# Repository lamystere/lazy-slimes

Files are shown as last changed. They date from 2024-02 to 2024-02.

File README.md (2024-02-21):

# lamystere's lazy slimes
#### Tutorial and 3d print files for the easiest slime build possible
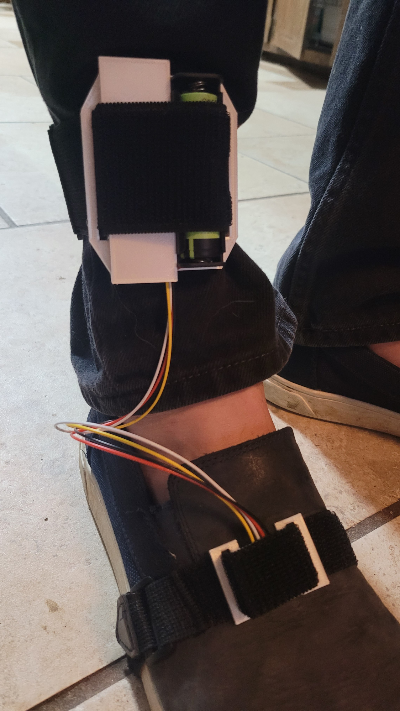
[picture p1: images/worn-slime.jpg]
a slime worn

### Pros  
- Quick to build: Each pair of trackers takes less than 15 minutes.
<sub><sup>(your soldering times may vary)</sup></sub>
- You'll have battery life for days.  About 36 hours run time.
- You can swap out low batteries for fresh ones.
- The only tools needed are a 3d printer, soldering iron, and scissors.
### Cons
- Putting batteries in backwards will kill your d1 board unless you add the diode!!!
- No battery percentage indication.
<sub><sup>(D1s will brown out before 18650s reach a harmfully low voltage.  Just be sure to remove the battery after the tracker dies or it will continue draining)</sup></sub>
- The battery makes it bigger than stock slimes. Its the size of Frozen Slimes.
- You'll have to remove the batteries to charge them or turn off the slimes.

## Parts for 10 trackers: $51 using AliExpress, $87 using amazon  
-  4-pin 2.54mm JST cables+connectors:  $8 - 19  
([30cm x 20 for \$8 on AliExpress](https://www.aliexpress.us/item/3256804651533419.html) - These have right angle connectors included so you save $6)  
([100cm x 4 for \$11 on AliExpress](https://www.aliexpress.us/item/3256805863323549.html) - optional for longer runs to satellites)  
([30cm x 20 for \$8 on amazon](https://www.amazon.com/dp/B09JNZJXTF))  
([100cm x 5 for \$11 on amazon](https://www.amazon.com/Kidisoii-Connector-Pre-Crimped-Housing-Adapter/dp/B0BW9T2L26) - optional for longer runs to satellites)  
-  4 pin female right-angle JST connectors:  $6  <sub><sup>(not needed if sourced from AliExpress)</sup></sub>  
([bag of 50 for \$6](https://www.amazon.com/dp/B0BMDQLR4Q))  
- D1 Minis: \$5 - \$15 for 10 tracking points  
([$1 each at AliExpress](https://www.aliexpress.us/item/3256805974392372.html))  
([$3 each at amazon](https://www.amazon.com/dp/B081PX9YFV))  
<sub><sup>([Tiel brought to my attention the Wemos Wroom has an integrated 18650 for roughly the same price.  Maybe that will be the next version.](https://www.aliexpress.us/item/3256804461622366.html)</sup></sub>
- BMI 160s: \$15 - \$21 for 10 tracking points  
([$1.50 each from AliExpress](https://www.aliexpress.us/item/3256805412351566.html))  
([$2 each at amazon if you can't wait, but buyer beware](https://www.amazon.com/dp/B0C4TMKL3V))*  
<sub><sup>*I linked ones that worked for me but you should avoid Amazon due to flaky QA.  You may get up to 50% DOA from some sellers.</sup></sub>
- Battery holders: \$6 - \$8  
([10 for \$6 on aliexpress](https://www.aliexpress.us/item/3256805903232291.html))  
([10 for \$8 on amazon](https://www.amazon.com/HiLetgo-10pcs-Battery-Holder-Storage/dp/B00LSG5BKO))   
- 18650 batteries and charger: \$16 - \$29 + optional \$12 - \$20 for a bigger charger  
([\$16 for 8 batteries and 2 bay charger](https://www.aliexpress.us/item/3256806110185068.html) on AliExpress)  
([\$12 for an 8 slot charger](https://www.aliexpress.us/item/3256806302334830.html) on AliExpress)  
([6 batteries and 4 slot charger for $29 on amazon](https://www.amazon.com/Tokeyla-Rechargeable-6-Button-top-B%EF%BF%B5at%EF%BF%B5t%EF%BF%B5%EF%BF%B5ery-Ba%EF%BF%B5tt%EF%BF%B5%EF%BF%B5er%EF%BF%B5y/dp/B0CBRDVHTY/))  
(or [6 batteries and 2 slot charger for $25](https://www.amazon.com/1%EF%BF%B58%EF%BF%B56%EF%BF%B550-Rechargeable-Batter%EF%BF%B5y-Universal-Batteries/dp/B0CLZTS43N/) on amazon)  
([6 bay charger for $17](https://www.amazon.com/Battery-Universal-Rechargeable-Batteries-Compatible/dp/B091GDK56V) on amazon)  
- 1n5817 Diodes: <sub><sup>(optional protection from putting the battery in backwards.  You should probably be less lazy than me and get them.)</sup></sub>  
[$5 for 100 at AliExpress](https://www.aliexpress.us/item/3256806265356485.html)  
[$7 for 100 at amazon](https://www.amazon.com/100-Pieces-1N5817-Schottky-Rectifier/dp/B079KDQQPD)  
- 3d printed cases: priceless  
- I'm assuming you have a soldering iron  

### Straps:
Consult [the slime VR docs for some good DIY strap ideas](https://docs.slimevr.dev/diy/diy-straps.html) to match your sewing skills.  Stretchy straps are very necessary! Regular velcro/nylon will fall right off.  If you just want to buy everything here's the amazon solution for \$40:
-  Stretchy 1" and 2" straps:  $26
([two of these at \$13](https://www.amazon.com/dp/B08CDGZ774))
([or one and this pack for \$12](https://www.amazon.com/VELCRO-Brand-VEL-30794-AMS-Stretchable-Umbrellas/dp/B09QSYVP5H))
- Chest harness: \$14
([\$14 for the cheapest gopro holder](https://www.amazon.com/dp/B01D3I8A7A))

# Cases
These are modeled after [Frozen Slimes](https://github.com/frosty6742/frozen-slimes-v2) but without the fancy PCB.  If you just want to print them you can use the [included STL files](/case-files/stl/) to slice and print.  If you have an Ender3 and PLA you can skip slicing and use the [included gcode files](/case-files/gcode%20for%20ender3/).  
   
The [master file](/case-files/lazy-slimes.scad) is written in [OpenSCAD](https://openscad.org/). You will need to use that to customize it (Fork it and send me a PR!).  Check out the parameters at the top for isolating each piece.  
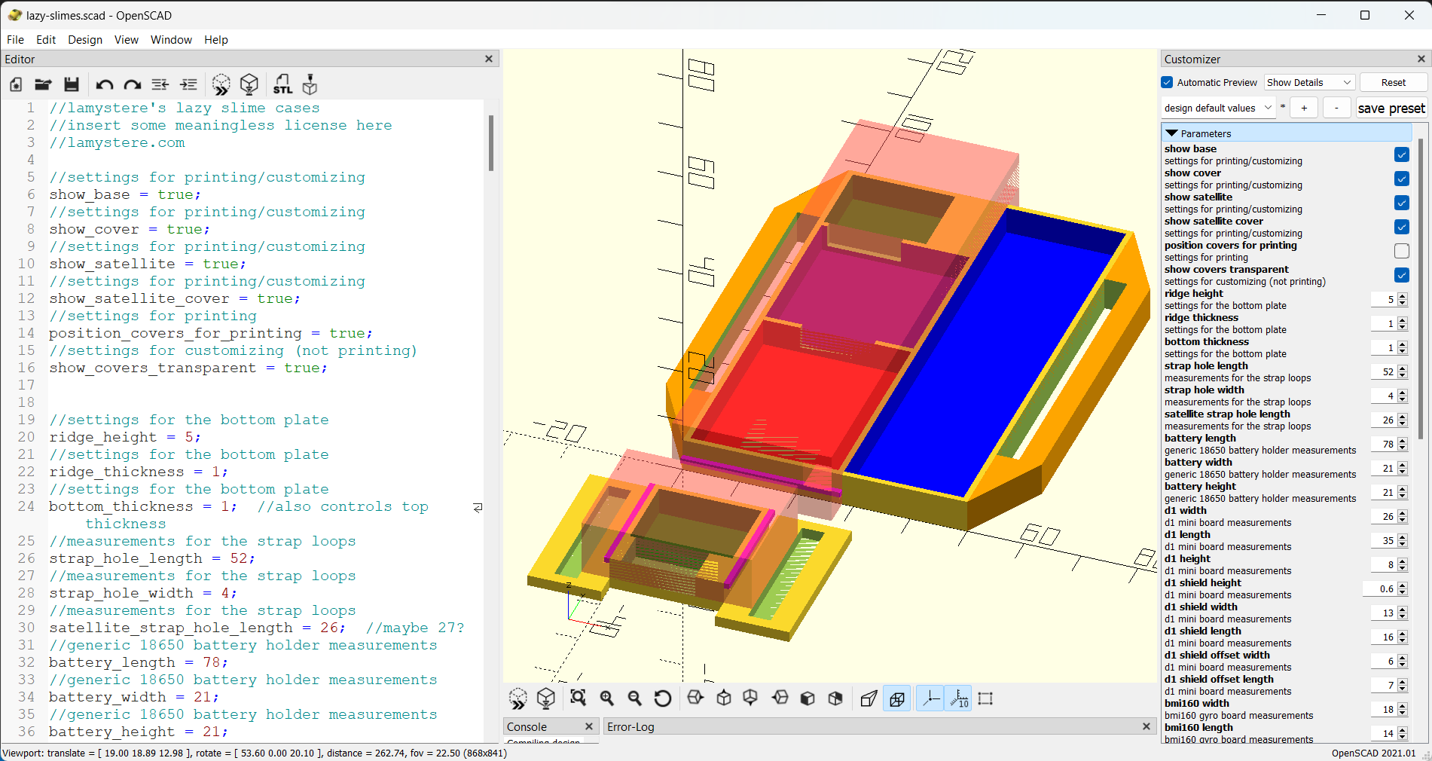
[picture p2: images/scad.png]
screen shot of scad file


# Building
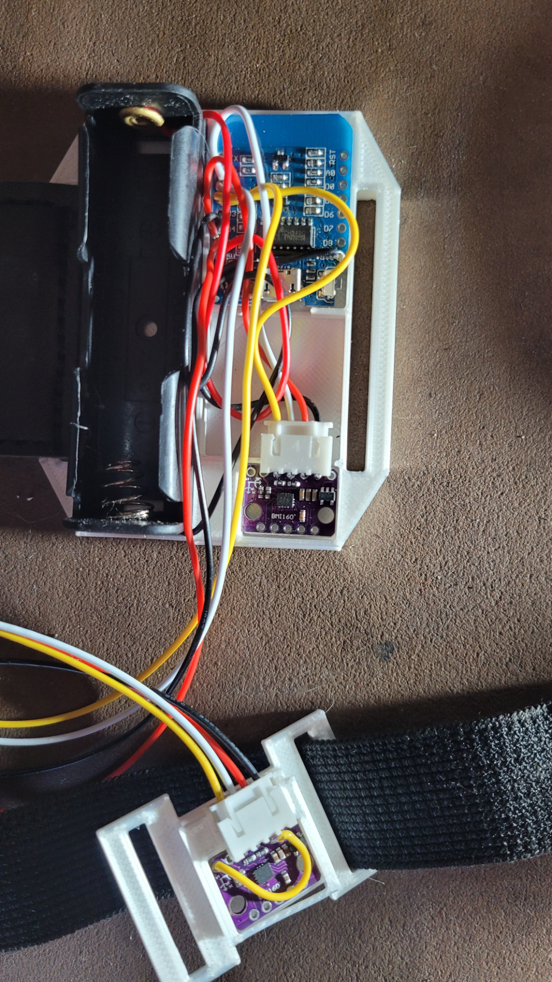
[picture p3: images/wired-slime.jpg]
a wired slime tracker

<sub><sup>(youtube walk-through is in the works)</sup></sub>

1. Cut one of the 4 pin jst cables to about the length of the case and strip the ends of the now shorter cable.
1. Solder the right angle connectors to the BMI160 boards covering the pins from 3v3 to SDA on the side with the parts.
2. Plug the long and short cables in to the BMI160s so you can follow the pad labels. Use the 100cm cables for longer runs like waist to chest or waist to thighs.  The cheaper 30cm cables should be enough for all the rest.  
<sub><sup> If you want to save \$11 you could omit the 100cm cables and make extensions by soldering a female jst connector onto a 30cm cable.  
If you don't need a satellite sensor connected you can skip the longer cable entirely.</sup></sub>
1. Use a scrap of the wire you just cut to solder a jumper on the satellite BMI160 from the G pad to the SAO pad. <sub><sup>This is necessary to identify it as sensor #2 on the data bus.</sup></sub>
1. Insert the battery ground wire and the ground wire for both BMI160s* into the G pad on the D1.  This is the trickiest part of the build but all 3 WILL fit in the hole.  Solder them all in. <sub><sup>(*note: to keep things quick ignore the color of the jst wires.  The G wire should be the second pad from the top on the BMI160)</sup></sub>
1. Solder the red battery wire into the 5V pad of the D1.  If you chose to get protection diodes then cut the red wire from the front of the battery holder and solder the diode there.  Reattach the red wire to the end of the diode with the ring painted on it.
1. Solder both of the 3V3 leads from the BMI160s to the 3V3 pad of the D1
1. Solder both of the SCL leads from the BMI 160s to the D1 pad of the D1
1. Solder both of the SDA leads from the BMI 160s to the D2 pad of the D1
1. Configure and connect to the wifi and Slime Server using a usb cable to the D1.  Configure and upload Slime firmware to the D1 first if you haven't already.  [Instructions](https://docs.slimevr.dev/firmware/index.html) and <a href="data:text/plain;charset=utf-8,%23define%20IMU%20IMU_BMI160%0A%23define%20SECOND_IMU%20IMU_BMI160%0A%23define%20BOARD%20BOARD_WEMOSD1MINI%0A%23define%20IMU_ROTATION%20DEG_90%0A%23define%20SECOND_IMU_ROTATION%20DEG_90%0A%0A%23define%20PRIMARY_IMU_OPTIONAL%20false%0A%23define%20SECONDARY_IMU_OPTIONAL%20true%0A%0A%23define%20MAX_IMU_COUNT%202%0A%0A%23ifndef%20IMU_DESC_LIST%0A%23define%20IMU_DESC_LIST%20%5C%0A%20%20%20%20IMU_DESC_ENTRY(IMU%2C%20%20%20%20%20%20%20%20PRIMARY_IMU_ADDRESS_ONE%2C%20%20%20IMU_ROTATION%2C%20%20%20%20%20%20%20%20PIN_IMU_SCL%2C%20PIN_IMU_SDA%2C%20PRIMARY_IMU_OPTIONAL%2C%20%20%20PIN_IMU_INT)%20%5C%0A%20%20%20%20IMU_DESC_ENTRY(SECOND_IMU%2C%20SECONDARY_IMU_ADDRESS_TWO%2C%20SECOND_IMU_ROTATION%2C%20PIN_IMU_SCL%2C%20PIN_IMU_SDA%2C%20SECONDARY_IMU_OPTIONAL%2C%20PIN_IMU_INT_2)%0A%23endif%0A%0A%2F%2F%20Battery%20monitoring%20options%20(comment%20to%20disable)%3A%0A%2F%2F%20BAT_EXTERNAL%20for%20ADC%20pin%2C%20BAT_INTERNAL%20for%20internal%20-%20can%20detect%20only%20low%20battery%2C%20BAT_MCP3021%20for%20external%20ADC%0A%23define%20BATTERY_MONITOR%20BAT_EXTERNAL%0A%23define%20BATTERY_SHIELD_RESISTANCE%20180%20%2F%2F130k%20BatteryShield%2C%20180k%20SlimeVR%20or%20fill%20in%20external%20resistor%20value%20in%20kOhm%0A%0A%23define%20PIN_IMU_SDA%20D2%0A%23define%20PIN_IMU_SCL%20D1%0A%23define%20PIN_IMU_INT%20D5%0A%23define%20PIN_IMU_INT_2%20D6%0A%23define%20PIN_BATTERY_LEVEL%20A0%0A">defines.h</a>
1. Place the BMI160 with the shorter wires into the top of the main case, the D1 into the bottom with wifi shield down, and the battery holder into the longest slot.
1. Place the base and cover on a flat surface to help line them up.  Slide the cover over the electronics.  Tuck the shorter cable and battery wires under the cover as you slide it.  Run the longer cable out the notch in the top or bottom. 
<sub><sup>To keep all BMI160 sensors pointed towards the ceiling you should run it through the hole nearest to the BMI160.  The BMI160 connector should always point towards the ceiling.  If that's not convenient you could [re-flash your firmware to customize the sensor orientation](https://docs.slimevr.dev/firmware/configuring-project.html#configuring-definesh-automatically).  Feet seem to be the exception.</sup></sub>  
1. Insert the satellite sensor into its little case and slide the cover over it
1. Thread the straps through the sides of cases over the battery slot so it can hold the battery in.  
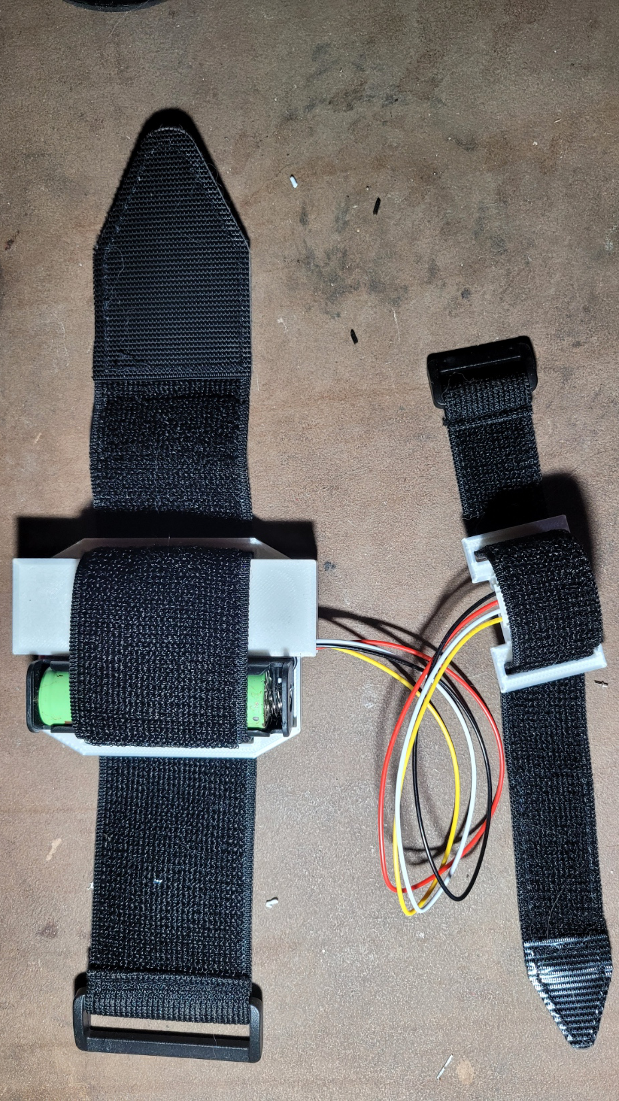
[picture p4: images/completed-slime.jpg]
a completed slime tracker


# Placement example
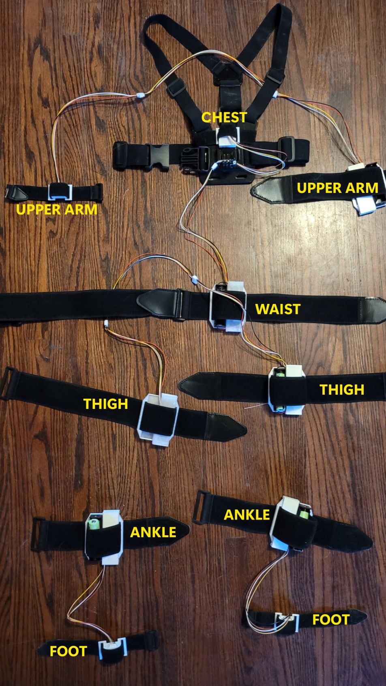
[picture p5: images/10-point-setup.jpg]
a 10 tracking point setup

1. Make sure all BMI160s have the connectors facing the ceiling (except the feet).  You may want to draw an arrow on the cover to indicate the "up" side of the tracker.
1. Combine 2 straps to reach around your waist.  
1. Notice that for one thigh I used a full size case just to hold a BMI160.  This is to accomodate needing a 2" strap to reach around a thigh.  I thread the cord over the waistband so it doesn't float between my legs.  <sub><sup>This would be a good case for having 2 independent trackers, but for this example of 5 trackers with 5 satellites I think it works best.  Some people connect one thigh to the waist sensor and the other thigh to the hip sensor.</sup></sub>
1. Its a similar dilemma with the upper arm sensors, but the 1" strap can reach around my bicep so its easier to keep to the standard setup and simply have a longer cord.  Notice I used 30cm extension cables rather than starting with a 100cm cable.

#### 12 point example:
Same except with lower arms.  Some may prefer shoulders instead.  
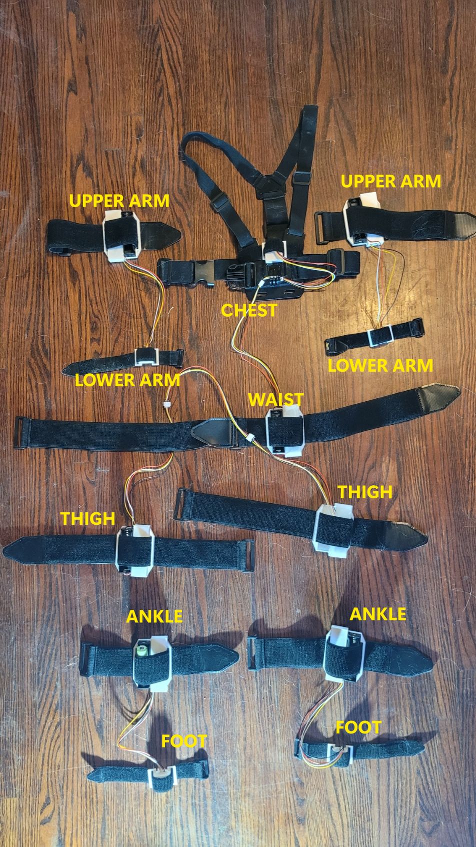
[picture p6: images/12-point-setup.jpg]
a 12 tracking point setup
  
Why not add in another 4 and get upper chest, waist, shoulders and lower arms?  Why stop there?  With 20 points you could get head, neck, and hands too and ditch the HMD for mocap purposes.  Then you only need finger tracking gloves!  And don't forget to strap a phone on to capture your face!

# Putting it on
1. Loosen the straps and insert all the batteries.  
<sub><sup>(Put red tape on the positive end of both the battery and the holder if you're worried you might accidentally insert it backwards)</sup></sub>
1. Tap the trackers while watching the slime server to confirm they are all connected and which is which.
1. Sit down and put on the waist band first.
1. Put on the harness with the chest sensor.
1. Strap remaining sensors around arms, legs and feet.
1. [Calibrate](https://docs.slimevr.dev/server/imu-calibration.html), [calibrate](https://docs.slimevr.dev/server/configuring-trackers.html), [calibrate](https://docs.slimevr.dev/server/body-config.html)!
1. Dance, dance, dance!
1. Remove the batteries to turn them off or when you need to charge.

# Thanks
Thanks to Gorbit99 and Tiel for suggesting improvements to this build!

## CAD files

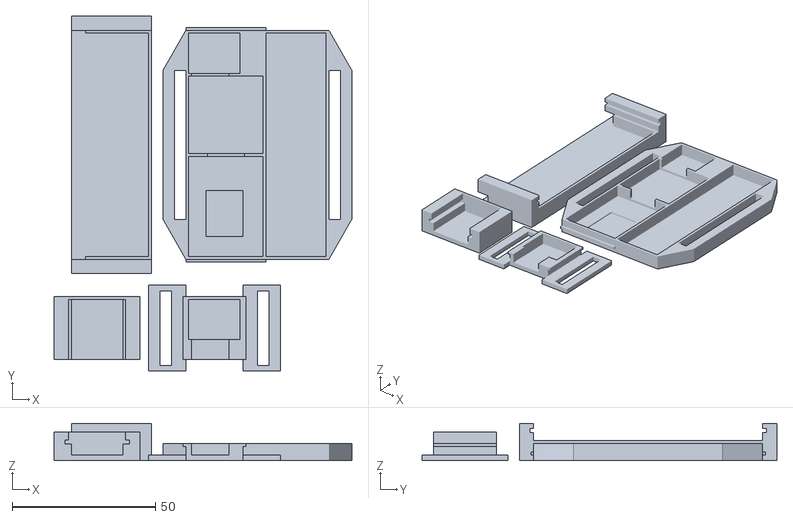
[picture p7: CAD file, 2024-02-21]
case-files/stl/whole_set.stl
104.0 x 124.0 x 13.0

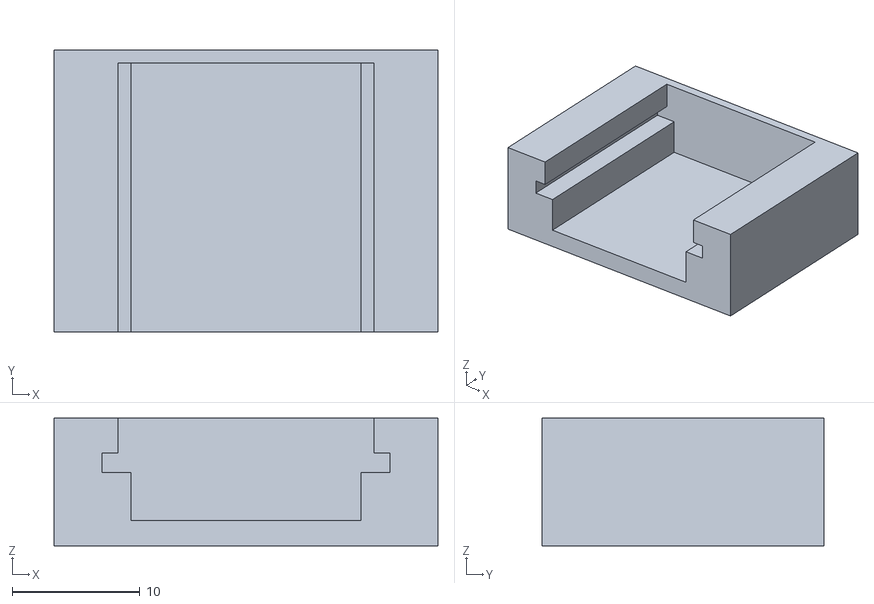
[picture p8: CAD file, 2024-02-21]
case-files/stl/satellite_cover.stl
30.0 x 22.0 x 10.0

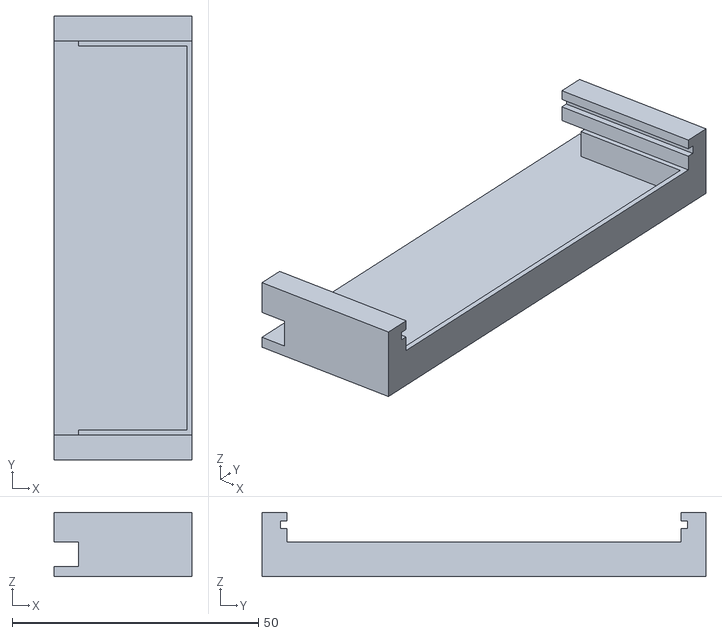
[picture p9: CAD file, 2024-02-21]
case-files/stl/cover.stl
28.0 x 90.0 x 13.0

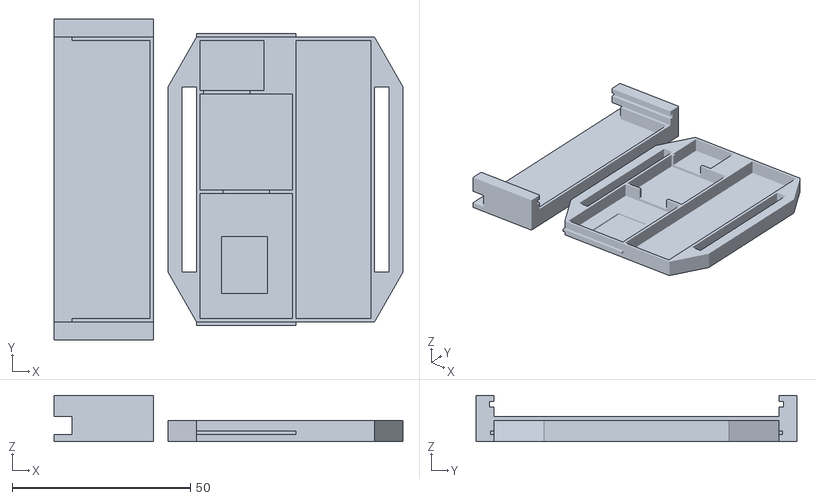
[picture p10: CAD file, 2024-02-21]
case-files/stl/base_and_cover.stl
98.0 x 90.0 x 13.0

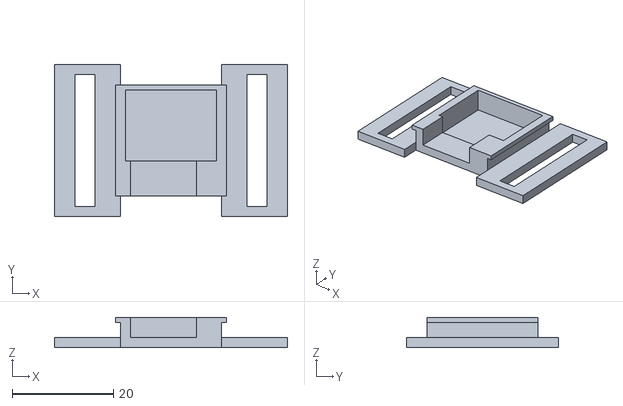
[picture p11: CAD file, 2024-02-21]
case-files/stl/satellite_base.stl
46.0 x 30.0 x 6.00

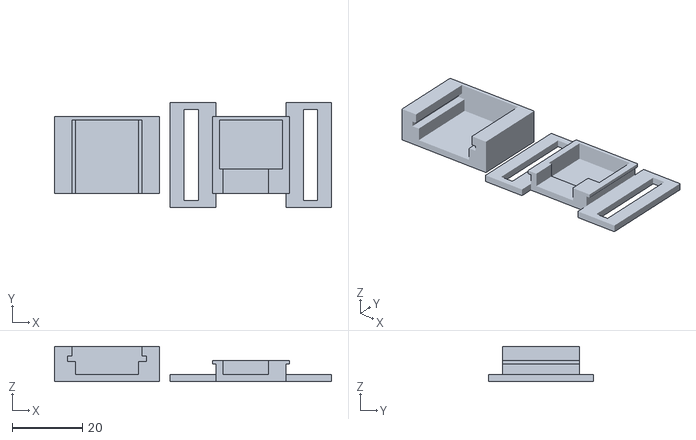
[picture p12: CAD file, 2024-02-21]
case-files/stl/satellite_and_cover.stl
79.0 x 30.0 x 10.0

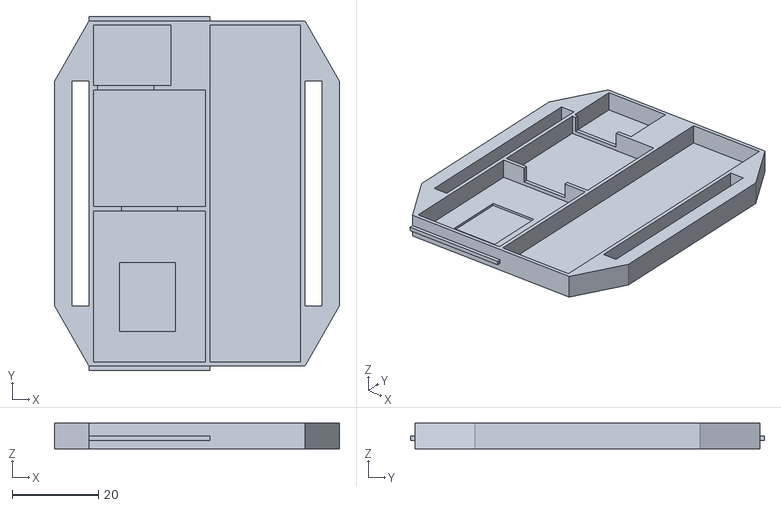
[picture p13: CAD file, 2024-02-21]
case-files/stl/base.stl
66.0 x 82.0 x 6.00

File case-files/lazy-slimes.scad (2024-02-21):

//lamystere's lazy slime cases
//insert some meaningless license here
//lamystere.com

//settings for printing/customizing
show_base = true;
//settings for printing/customizing
show_cover = true;
//settings for printing/customizing
show_satellite = true;
//settings for printing/customizing
show_satellite_cover = true;
//settings for printing
position_covers_for_printing = true;
//settings for customizing (not printing)
show_covers_transparent = true;


//settings for the bottom plate
ridge_height = 5;
//settings for the bottom plate
ridge_thickness = 1;
//settings for the bottom plate
bottom_thickness = 1;  //also controls top thickness
//measurements for the strap loops
strap_hole_length = 52;
//measurements for the strap loops
strap_hole_width = 4;
//measurements for the strap loops
satellite_strap_hole_length = 26;  //maybe 27?
//generic 18650 battery holder measurements
battery_length = 78;
//generic 18650 battery holder measurements
battery_width = 21;
//generic 18650 battery holder measurements
battery_height = 21;
//d1 mini board measurements
d1_width = 26;
//d1 mini board measurements
d1_length = 35;
//d1 mini board measurements
d1_height = 8;
//d1 mini board measurements
d1_shield_height = .6;
//d1 mini board measurements
d1_shield_width = 13;
//d1 mini board measurements
d1_shield_length = 16;
//d1 mini board measurements
d1_shield_offset_width = 6;
//d1 mini board measurements
d1_shield_offset_length = 7;
//bmi160 gyro board measurements
bmi160_width = 18;
//bmi160 gyro board measurements
bmi160_length = 14;
//bmi160 gyro board measurements
bmi160_height = 5; //4
//bmi160 gyro board 
bmi160_use_straight_pins = true; //
main_width = d1_width + battery_width + ridge_thickness * 3;
main_length = battery_length + ridge_thickness * 2;
//the 4 pin connector on the bmi160
connector_width = 13;
//the 4 pin connector on the bmi160
connector_height = 9;
//the 4 pin connector on the bmi160
connector_depth = 7;
//the 4 pin connector on the bmi160
connector_offset_z = 1;
//the 4 pin connector on the bmi160
connector_offset_y = 1;
//the 4 pin connector pushes the board up
solder_height = 2; 
//cant make lid slides an exact match, the outer channel must be a hair bigger
slide_tolerance = .5; 
//how thick the grooved sides of the covers are
slide_thickness = 5; //below 4 is too flimsy
//how thick the rail and groove are
slide_rail_thickness = 1;
//the hole at the side where the wire to the satellite runs
cable_run_width = 5; 


if (show_base) {base();}
if (show_cover) {
    if (position_covers_for_printing) {
        translate([-strap_hole_width*3,0,bottom_thickness*2 + connector_height + solder_height]) rotate([0,180,0])  cover(); 
    } else {
        if (show_covers_transparent) {
            #cover(); 
        } else {
            cover(); 
        }
    }
}

translate([0,-satellite_strap_hole_length-strap_hole_width-slide_thickness,0]) {
    if (show_satellite) {
        satellite();
    }
    if (show_satellite_cover) {
        if (position_covers_for_printing) {
            translate([-strap_hole_width*4-slide_thickness,0,bottom_thickness + connector_height + solder_height]) rotate([0,180,0])  satellite_cover();
        } else {
           if (show_covers_transparent) {
               #satellite_cover(); 
           } else {
               satellite_cover(); 
           }
        } 
    }
}

module base() {
    difference() {
        translate([0,0,0]) cube([main_width,main_length,bottom_thickness + ridge_height]);

        translate([ridge_thickness,ridge_thickness,bottom_thickness]) d1();
        translate([ridge_thickness  + d1_width,0,bottom_thickness])battery();
            
        translate([ridge_thickness,main_length -ridge_thickness - bmi160_length,bottom_thickness]) scale([1,1,1.01]) bmi160();
            
        color("purple") translate([ridge_thickness,d1_length +ridge_thickness*2,bottom_thickness]) middle_compartment();
            
        
    }
    translate([0,-slide_rail_thickness,bottom_thickness*2]) slide_ridge(d1_width+ridge_thickness*2);
    translate([0,main_length,bottom_thickness*2])  slide_ridge(d1_width+ridge_thickness*2);

    strap();
    translate([main_width,0,0]) mirror([1,0,0]) strap();
}


module slide_ridge(width) {
    color("magenta") cube([width,slide_rail_thickness,slide_rail_thickness]);
    //translate([0,-ridge_thickness+slide_tolerance,0]) cube([d1_width+ridge_thickness*2,ridge_thickness-slide_tolerance,ridge_thickness-slide_tolerance]);
}

module middle_compartment() {
    cube([main_width - battery_width - ridge_thickness * 3, main_length - d1_length - bmi160_length - ridge_thickness * 4,ridge_height*2]);
}

module battery() {
        color("blue") translate([ridge_thickness,ridge_thickness,0]) cube([battery_width,battery_length,battery_height]);
}

module d1() {
    color("red")  cube([d1_width,d1_length,d1_height]);
    
    //connector
        translate([ connector_width/2,d1_length,connector_offset_z]) cube([connector_width,connector_depth,connector_height]);

    //wifi shield
        translate([ d1_shield_offset_width,d1_shield_offset_length,-d1_shield_height]) cube([d1_shield_width,d1_shield_length,d1_shield_height]);
}

module bmi160() {
    color("green")  cube([bmi160_width,bmi160_length,bmi160_height]);
    
    //connector
    translate([connector_offset_y,-connector_depth,connector_offset_z]) cube([connector_width,connector_depth,connector_height]);
}

module strap() {
    difference() {
    color("orange") linear_extrude(bottom_thickness + ridge_height) polygon([[0,0],[0,main_length],[-strap_hole_width * 2, main_length - ((main_length - strap_hole_length) / 2)], [-strap_hole_width * 2, (main_length - strap_hole_length) / 2],[0,0]]);
        
    translate([-strap_hole_width,(main_length - strap_hole_length) / 2,  -2]) cube([strap_hole_width,strap_hole_length,ridge_height * 2]);
    }
}


module cover() {
    color("cyan") {
        difference() {
            translate([0,-slide_thickness,ridge_height+bottom_thickness]) cube([d1_width+ridge_thickness*2,main_length+slide_thickness*2,bottom_thickness + connector_height + solder_height - ridge_height]);
        
        //inner volume
            translate([ridge_thickness,ridge_thickness,ridge_height+bottom_thickness])   cube([d1_width + ridge_thickness, main_length - ridge_thickness * 2,connector_height + solder_height - ridge_height - bottom_thickness]);
            
        //cable run
        translate([d1_width - cable_run_width/2 - ridge_thickness/2,-ridge_thickness*6,ridge_height+bottom_thickness]) cube([cable_run_width,main_length*1.2,connector_height - ridge_height + 1]);
        }
        
        //middle support
        //translate([d1_width*7/8+ridge_thickness*2,d1_length+ridge_thickness*2,ridge_height]) cube([d1_width/8,ridge_thickness,d1_height - ridge_height]);
    
        side_lock();
        translate([0,main_length,0]) mirror([0,1,0]) side_lock();
    }
}

module side_lock() {
    difference() {
        translate([0,-slide_thickness,0]) cube([d1_width+ridge_thickness*2,slide_thickness,ridge_height+bottom_thickness]);
        
        translate([0,-slide_rail_thickness-slide_tolerance/2,bottom_thickness*2-slide_tolerance/2]) cube([d1_width+ridge_thickness*2,slide_rail_thickness+slide_tolerance,slide_rail_thickness+slide_tolerance]);
    }
}

module satellite() {
    difference() {
        
        cube([bmi160_width + ridge_thickness * 2,bmi160_length + connector_depth + ridge_thickness,bmi160_height + bottom_thickness ]);
            
        //bottom cutout
        translate([ridge_thickness,connector_depth,bottom_thickness]) scale([1,1,1.01]) bmi160();
        
    }
    
    //ridge 1
    translate([0,0,bmi160_height+bottom_thickness-slide_rail_thickness]) rotate([0,0,90]) slide_ridge(bmi160_length + connector_depth + ridge_thickness);
    
    //ridge 2
    translate([bmi160_width+ridge_thickness *2+slide_rail_thickness,0,bmi160_height+bottom_thickness-slide_rail_thickness]) rotate([0,0,90]) slide_ridge(bmi160_length + connector_depth + ridge_thickness);
    
    //straps
    satellite_strap();
    translate([bmi160_width+ridge_thickness*2 ,bmi160_length + connector_depth + ridge_thickness,0]) 
    rotate([0,0,180]) satellite_strap();
}

module satellite_strap() {
    translate([0,(bmi160_length + connector_depth + ridge_thickness - satellite_strap_hole_length - strap_hole_width)/2  ,0]) {
        // 
    difference() {
        translate([-slide_thickness-strap_hole_width*2,0,0]) cube([strap_hole_width*2+slide_thickness,satellite_strap_hole_length + strap_hole_width,bottom_thickness + connector_offset_z]);
        
        translate([-strap_hole_width-slide_thickness,strap_hole_width/2,0]) cube([strap_hole_width,satellite_strap_hole_length,bmi160_height]);
    }
    }
}
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
